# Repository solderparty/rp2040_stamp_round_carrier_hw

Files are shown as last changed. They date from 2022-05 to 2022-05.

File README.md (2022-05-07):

# The RP2040 Stamp Round Carrier

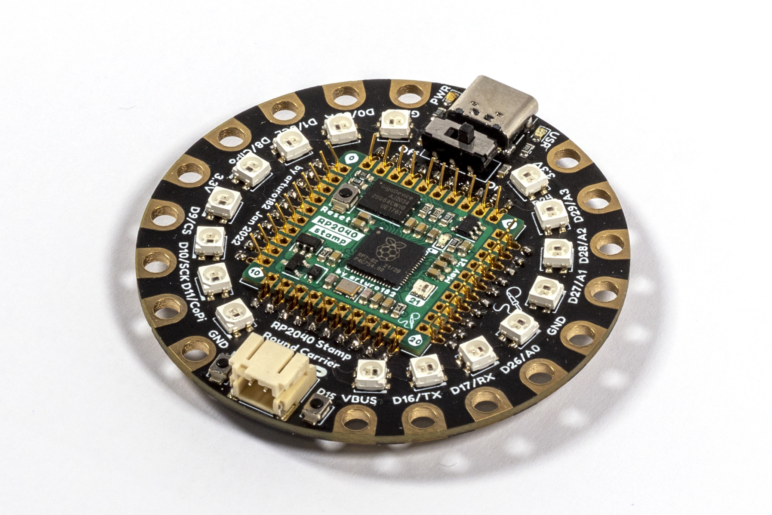
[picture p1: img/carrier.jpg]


The RP2040 Stamp Round Carrier is a reference design for the RP2040 Stamp as well as a full-fledged round RP2040 dev board.
The HW files for the Stamp can be found here: https://github.com/solderparty/rp2040_stamp_hw

The Carrier comes with a combo 3-in-1 SMD/TH/FlexyPin Stamp footprint, you can solder the Stamp directly to the Carrier, use 2mm pin headers + sockets to be able to plug it in and out, or use FlexyPins to pop the Stamp in and out of the Carrier would soldering the Stamp. This way the Carrier also acts as a great Stamp flashing and testing jig.

On top of all the functionality of the Stamp, the Carrier also adds:
* A ring of 16 Neopixels
* Combo 3-in-1 Stamp footprint (SMD/TH/FlexyPin)
* Sewing (conductive thread) and alligator clip-friendly pads
* An on/off switch
* 3.7/4.2V LiPo connector
* USR LED
* Power (3.3V) LED
* Two user buttons
* USB Type-C connector

# Links

For more information visit https://rp2040-stamp.solder.party/

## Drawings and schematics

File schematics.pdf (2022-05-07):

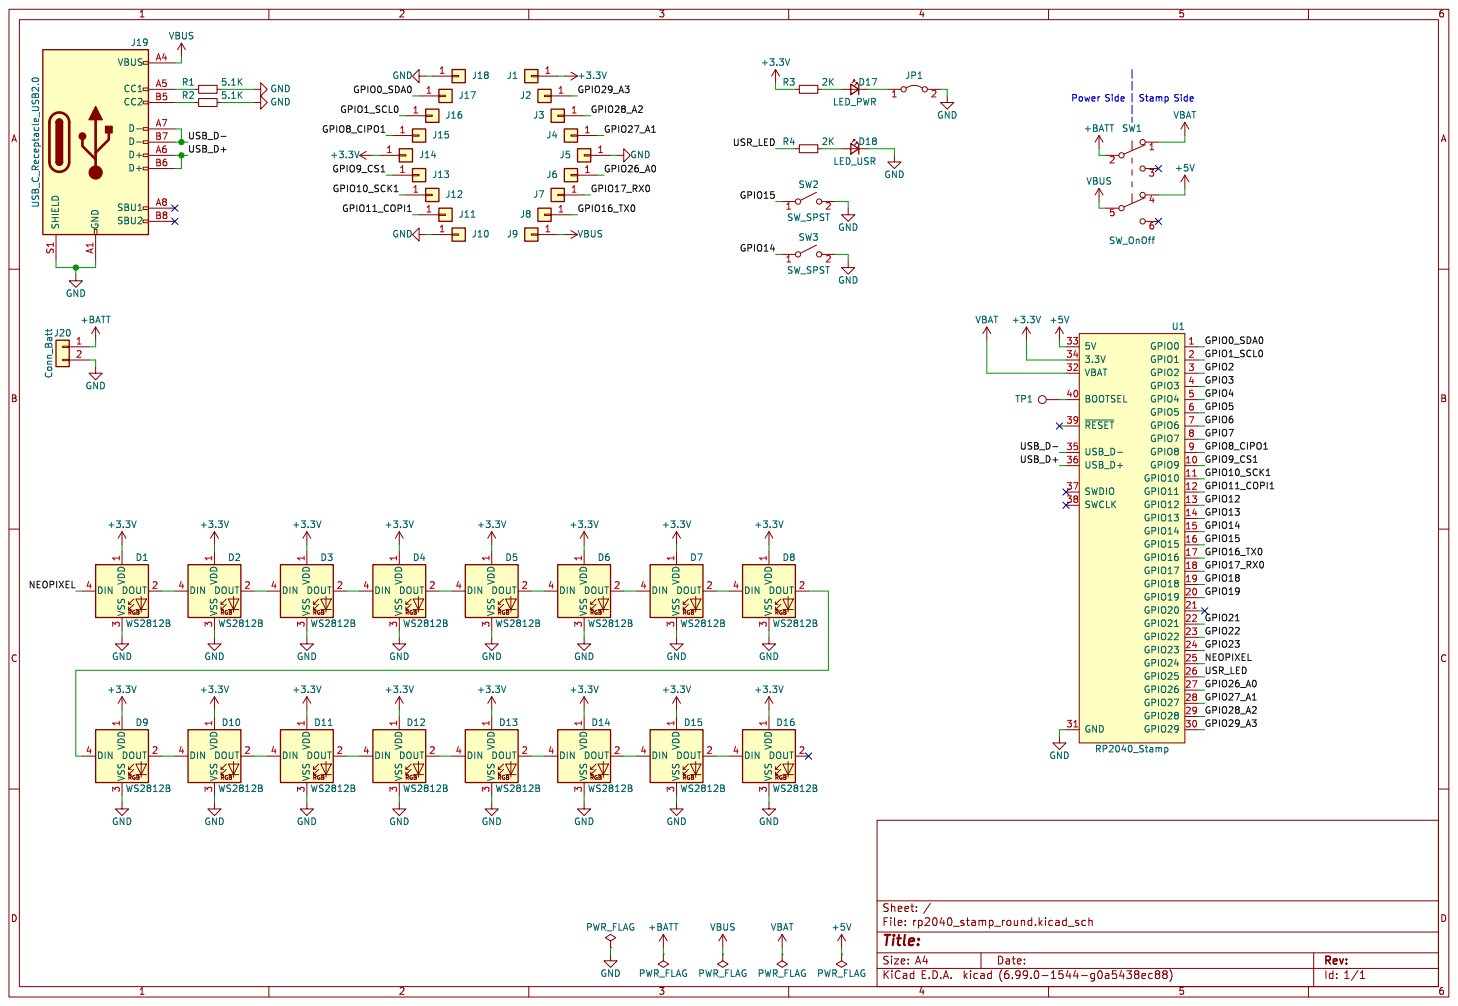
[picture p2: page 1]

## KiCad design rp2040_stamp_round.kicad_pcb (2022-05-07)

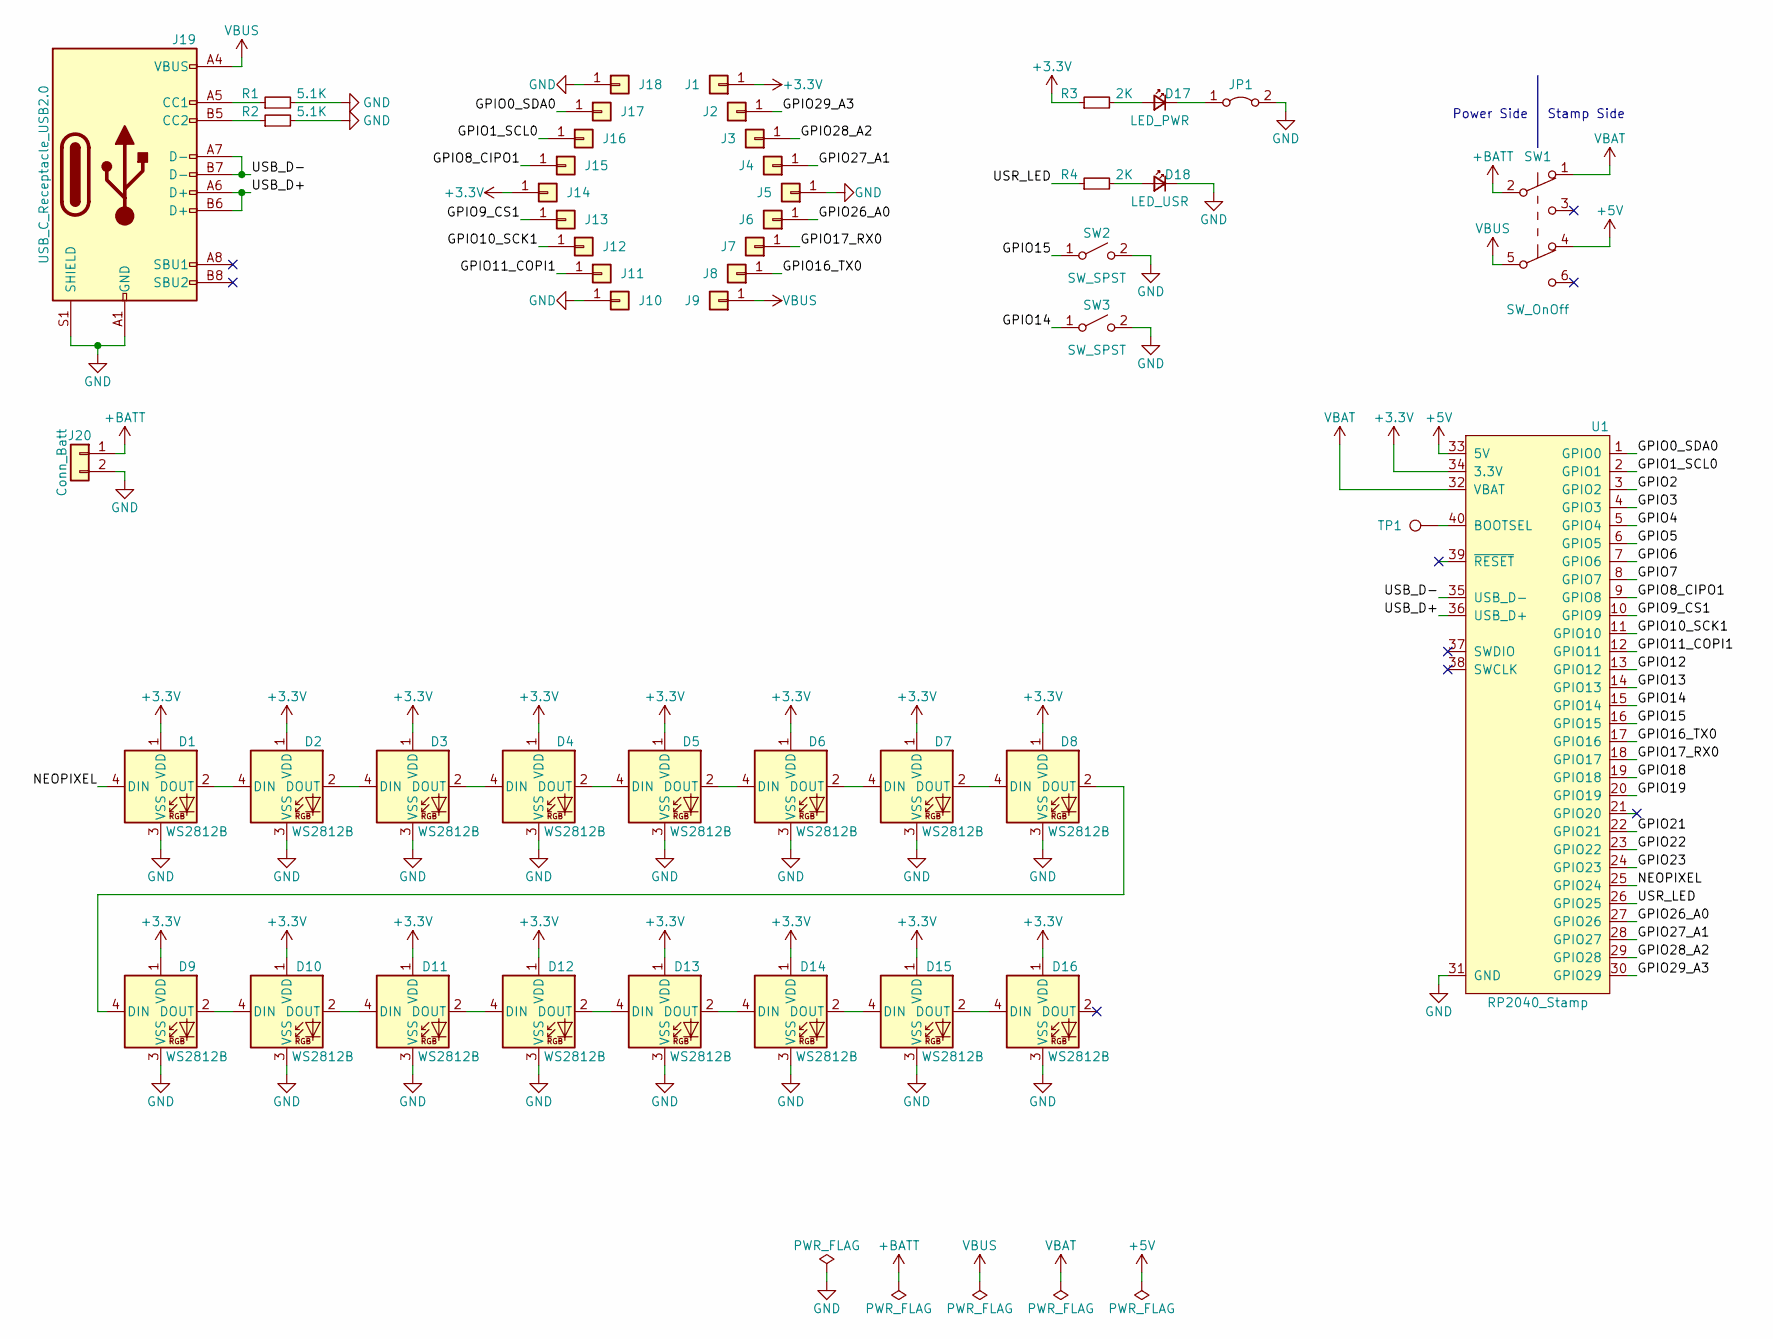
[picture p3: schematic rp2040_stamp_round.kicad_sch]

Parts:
D1, D2, D3, D4, D5, D6, D7, D8, D9, D10, D11, D12, D13, D14, D15, D16: WS2812B; LED_WS2812B_PLCC4_3.5x3.5mm_P1.78mm; LCSC C527089
D17: LED_PWR; LED_0603_1608Metric
D18: LED_USR; LED_0603_1608Metric
J1, J2, J3, J4, J5, J6, J7, J8, J9, J10, J11, J12, J13, J14, J15, J16, J17, J18: Conn_01x01; MountingHole_3.2mm_M3_Pad_Polygon
J19: USB_C_Receptacle_USB2.0; USB_C_Receptacle_XKB_U262-16XN-4BVC11; LCSC C319148
J20: Conn_Batt; JST_PH_S2B-PH-SM4-TB_1x02-1MP_P2.00mm_Horizontal; LCSC C47647
JP1: Jumper_PWR; SolderJumper-2_P1.3mm_Bridged_RoundedPad1.0x1.5mm
R1, R2: 5.1K; R_0603_1608Metric
R3, R4: 2K; R_0603_1608Metric
SW1: SW_OnOff; SW_DPDT_CK_JS202011JCQN; LCSC C221665
SW2, SW3: SW_SPST; SW_SPST_B3U-1000P-B; LCSC C561514
TP1: TP_BOOTSEL; TestPoint_Pad_D2.0mm
U1: RP2040_Stamp; RP2040_Stamp_Springs

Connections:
+3V3: D1.1 (VDD), D2.1 (VDD), D3.1 (VDD), D4.1 (VDD), D5.1 (VDD), D6.1 (VDD), D7.1 (VDD), D8.1 (VDD), D9.1 (VDD), D10.1 (VDD), D11.1 (VDD), D12.1 (VDD), D13.1 (VDD), D14.1 (VDD), D15.1 (VDD), D16.1 (VDD), J1.1, J14.1, R3.1, U1.34 (3.3V)
+5V: SW1.4 (A), U1.33 (5V)
+BATT: J20.1, SW1.2 (B)
/GPIO0_SDA0: J17.1, U1.1 (GPIO0)
/GPIO1_SCL0: J16.1, U1.2 (GPIO1)
/GPIO2: U1.3 (GPIO2)
/GPIO3: U1.4 (GPIO3)
/GPIO4: U1.5 (GPIO4)
/GPIO5: U1.6 (GPIO5)
/GPIO6: U1.7 (GPIO6)
/GPIO7: U1.8 (GPIO7)
/GPIO8_CIPO1: J15.1, U1.9 (GPIO8)
/GPIO9_CS1: J13.1, U1.10 (GPIO9)
/GPIO10_SCK1: J12.1, U1.11 (GPIO10)
/GPIO11_COPI1: J11.1, U1.12 (GPIO11)
/GPIO12: U1.13 (GPIO12)
/GPIO13: U1.14 (GPIO13)
/GPIO14: SW3.1 (A), U1.15 (GPIO14)
/GPIO15: SW2.1 (A), U1.16 (GPIO15)
/GPIO16_TX0: J8.1, U1.17 (GPIO16)
/GPIO17_RX0: J7.1, U1.18 (GPIO17)
/GPIO18: U1.19 (GPIO18)
/GPIO19: U1.20 (GPIO19)
/GPIO21: U1.22 (GPIO21)
/GPIO22: U1.23 (GPIO22)
/GPIO23: U1.24 (GPIO23)
/GPIO26_A0: J6.1, U1.27 (GPIO26)
/GPIO27_A1: J4.1, U1.28 (GPIO27)
/GPIO28_A2: J3.1, U1.29 (GPIO28)
/GPIO29_A3: J2.1, U1.30 (GPIO29)
/NEOPIXEL: D1.4 (DIN), U1.25 (GPIO24)
/USB_D+: J19.A6 (D+), J19.B6 (D+), U1.36 (USB_D+)
/USB_D-: J19.A7 (D-), J19.B7 (D-), U1.35 (USB_D-)
/USR_LED: R4.1, U1.26 (GPIO25)
GND: D1.3 (VSS), D2.3 (VSS), D3.3 (VSS), D4.3 (VSS), D5.3 (VSS), D6.3 (VSS), D7.3 (VSS), D8.3 (VSS), D9.3 (VSS), D10.3 (VSS), D11.3 (VSS), D12.3 (VSS), D13.3 (VSS), D14.3 (VSS), D15.3 (VSS), D16.3 (VSS), D18.1 (K), J5.1, J10.1, J18.1, J19.A1 (GND), J19.A12 (GND), J19.B1 (GND), J19.B12 (GND), J19.S1 (SHIELD), J20.2, JP1.2 (B), R1.2, R2.2, SW2.2 (B), SW3.2 (B), U1.31 (GND)
unnamed: D1.2 (DOUT), D2.4 (DIN)
unnamed: D2.2 (DOUT), D3.4 (DIN)
unnamed: D3.2 (DOUT), D4.4 (DIN)
unnamed: D4.2 (DOUT), D5.4 (DIN)
unnamed: D5.2 (DOUT), D6.4 (DIN)
unnamed: D6.2 (DOUT), D7.4 (DIN)
unnamed: D7.2 (DOUT), D8.4 (DIN)
unnamed: D8.2 (DOUT), D9.4 (DIN)
unnamed: D9.2 (DOUT), D10.4 (DIN)
unnamed: D10.2 (DOUT), D11.4 (DIN)
unnamed: D11.2 (DOUT), D12.4 (DIN)
unnamed: D12.2 (DOUT), D13.4 (DIN)
unnamed: D13.2 (DOUT), D14.4 (DIN)
unnamed: D14.2 (DOUT), D15.4 (DIN)
unnamed: D15.2 (DOUT), D16.4 (DIN)
unnamed: D17.2 (A), R3.2
unnamed: D17.1 (K), JP1.1 (A)
unnamed: D18.2 (A), R4.2
unnamed: J19.A5 (CC1), R1.1
unnamed: J19.B5 (CC2), R2.1
unnamed: TP1.1, U1.40 (BOOTSEL)
VBAT: SW1.1 (A), U1.32 (VBAT)
VBUS: J9.1, J19.A4 (VBUS), J19.A9 (VBUS), J19.B4 (VBUS), J19.B9 (VBUS), SW1.5 (B)

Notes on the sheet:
Stamp Side
Power Side

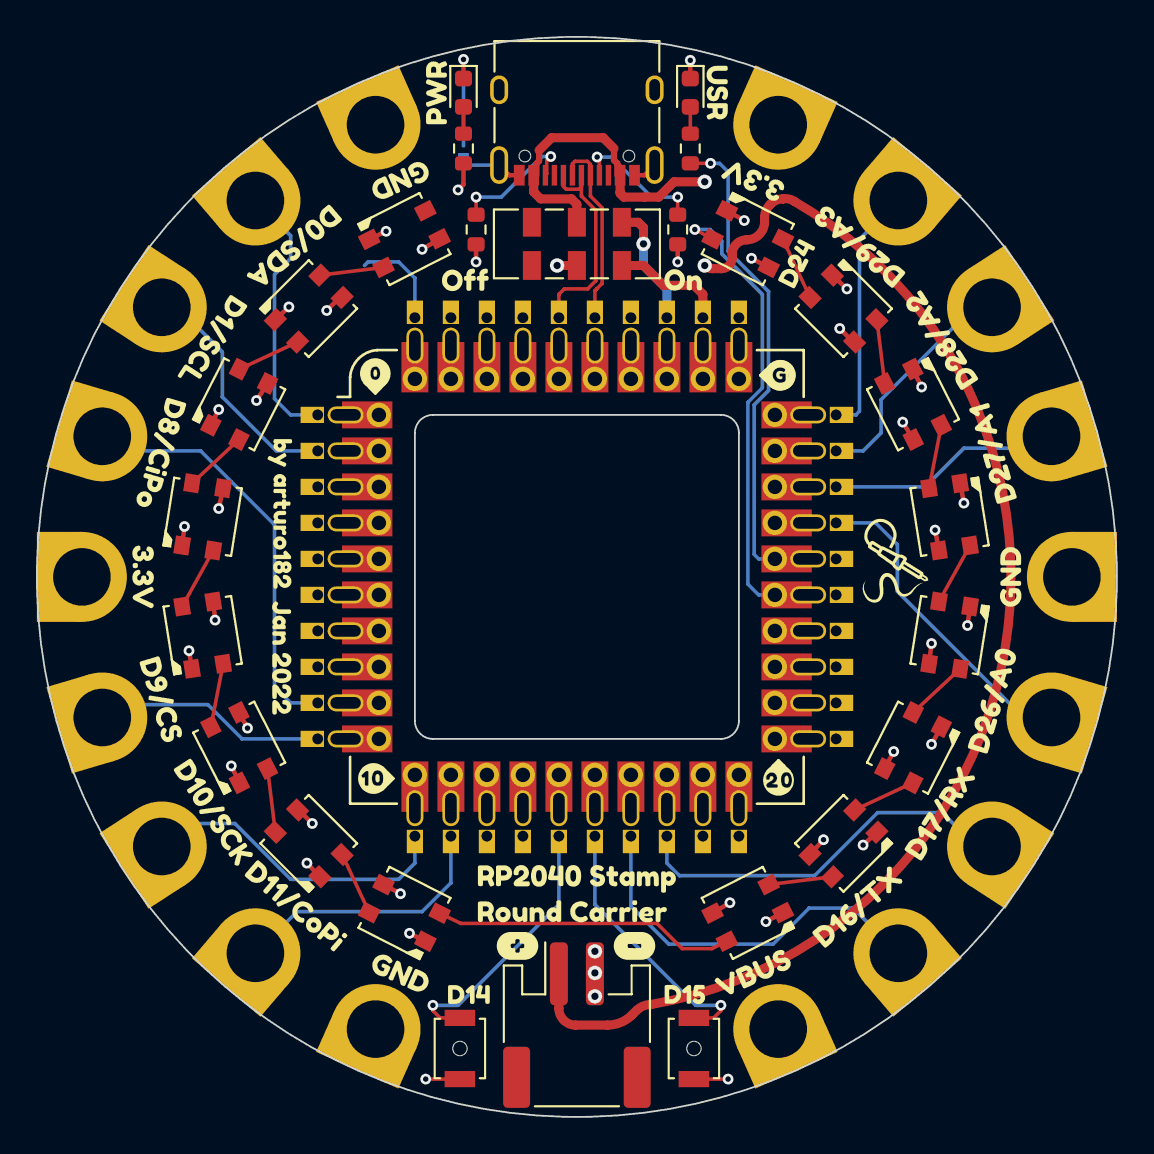
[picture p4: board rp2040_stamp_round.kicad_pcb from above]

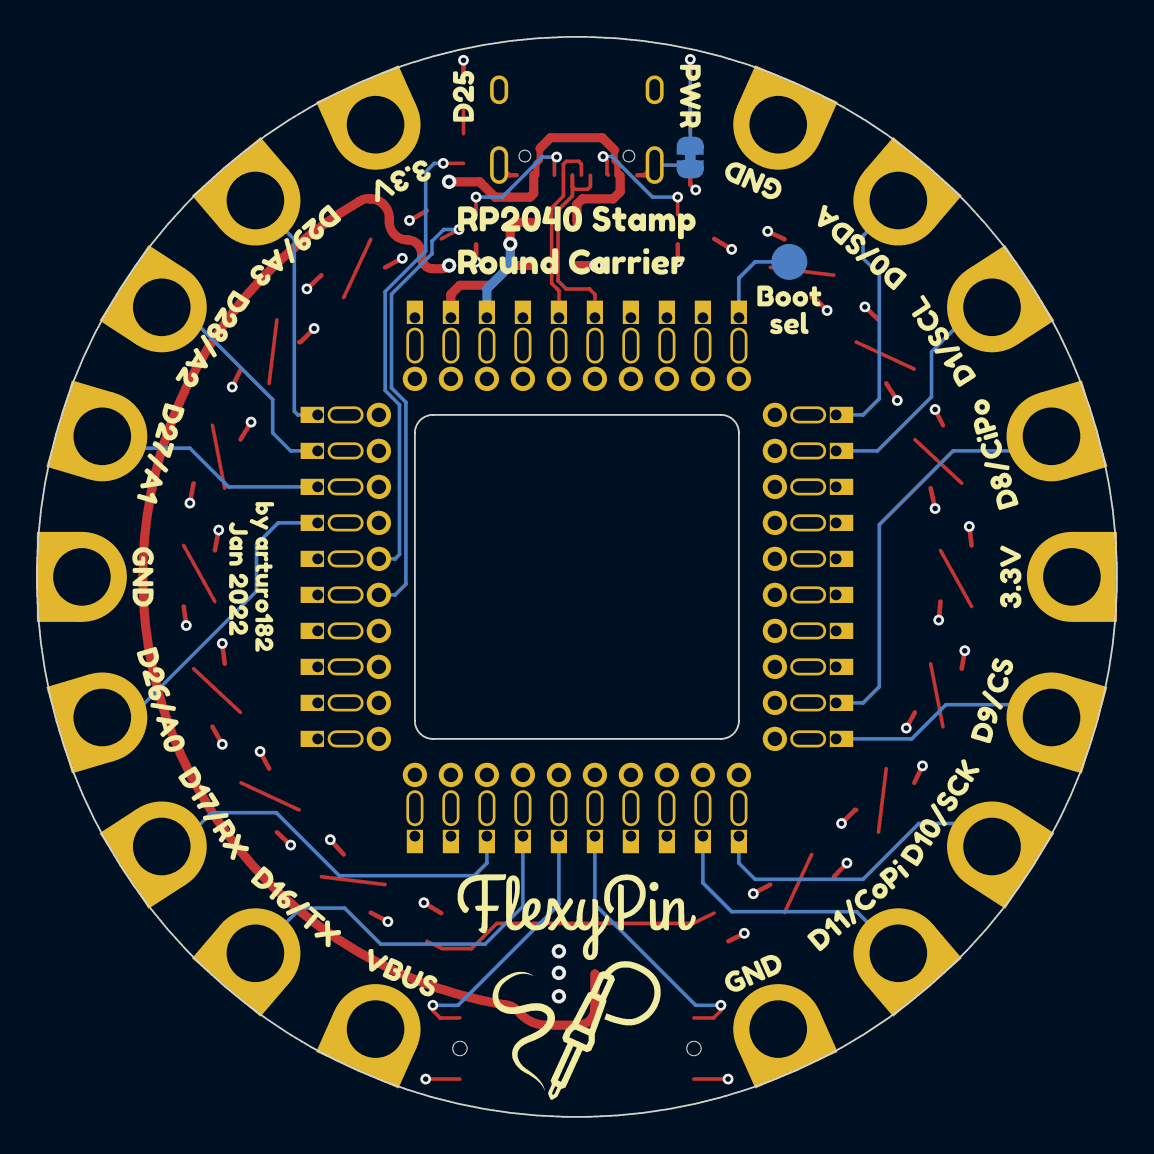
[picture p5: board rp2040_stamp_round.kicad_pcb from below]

Board: 4 copper layers, 60.0 x 60.0 mm, 103 parts (27 on the bottom side), 45 nets.

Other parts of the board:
kibuzzard-61B7CACE, kibuzzard-61B7CACE#2: G***; kibuzzard-61B7CACE
kibuzzard-61B7CB2A, kibuzzard-61B7CB2A#2, kibuzzard-61B7CB2A#3, kibuzzard-61B7CB2A#4: G***; kibuzzard-61B7CB2A
kibuzzard-61B7CB91, kibuzzard-61B7CB91#2, kibuzzard-61B7CB91#3, kibuzzard-61B7CB91#4, kibuzzard-61B7CB91#5, kibuzzard-61B7CB91#6: G***; kibuzzard-61B7CB91
kibuzzard-61B7F7A6, kibuzzard-61B7F7A6#2: G***; kibuzzard-61B7F7A6
kibuzzard-61B7F7BF, kibuzzard-61B7F7BF#2: G***; kibuzzard-61B7F7BF
kibuzzard-61B7F7D5, kibuzzard-61B7F7D5#2: G***; kibuzzard-61B7F7D5
kibuzzard-61B7F7FD, kibuzzard-61B7F7FD#2: G***; kibuzzard-61B7F7FD
kibuzzard-61B7F819, kibuzzard-61B7F819#2: G***; kibuzzard-61B7F819
kibuzzard-61B7FA9B, kibuzzard-61B7FA9B#2: G***; kibuzzard-61B7FA9B
kibuzzard-61B7FAB5, kibuzzard-61B7FAB5#2: G***; kibuzzard-61B7FAB5
kibuzzard-61B7FADB, kibuzzard-61B7FADB#2: G***; kibuzzard-61B7FADB
kibuzzard-61B7FB04, kibuzzard-61B7FB04#2: G***; kibuzzard-61B7FB04
kibuzzard-61B7FB19, kibuzzard-61B7FB19#2: G***; kibuzzard-61B7FB19
kibuzzard-61B7FB48, kibuzzard-61B7FB48#2: G***; kibuzzard-61B7FB48
kibuzzard-61B7FFB7: G***; kibuzzard-61B7FFB7
kibuzzard-61B788A5, kibuzzard-61B788A5#2: G***; kibuzzard-61B788A5
kibuzzard-61B789B2: G***; kibuzzard-61B789B2
kibuzzard-61B804DF: G***; kibuzzard-61B804DF
kibuzzard-61B804E7: G***; kibuzzard-61B804E7
kibuzzard-61B8067D: G***; kibuzzard-61B8067D
kibuzzard-61B8084E: G***; kibuzzard-61B8084E
kibuzzard-61B78991: G***; kibuzzard-61B78991
kibuzzard-61B80856: G***; kibuzzard-61B80856
kibuzzard-61BA2B21, kibuzzard-61BA2B21#2: G***; kibuzzard-61BA2B21
kibuzzard-61BA4CE2: G***; kibuzzard-61BA4CE2
kibuzzard-61DD95B3: G***; kibuzzard-61DD95B3
kibuzzard-61DD95E6: G***; kibuzzard-61DD95E6
kibuzzard-61DD95F0: G***; kibuzzard-61DD95F0
kibuzzard-61DD9534, kibuzzard-61DD9534#2: G***; kibuzzard-61DD9534
kibuzzard-61DD9594: G***; kibuzzard-61DD9594
kibuzzard-61E0313F: G***; kibuzzard-61E0313F
kibuzzard-61E03091: G***; kibuzzard-61E03091

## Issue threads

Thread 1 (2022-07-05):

Power Switch & Charging

cooltrooper, 2022-07-05:
Hello,

Just to check my understanding, due to the design of the stamp and this carrier, charging of the battery only takes place when the power switch is on?

Thanks

arturo182, 2022-07-06:
Yes, that is correct. The power switch disconnects the battery and the USB power. This is by design :)

Closed 2022-07-06.

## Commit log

2021-12-15 Rev 1
    [rp2040_stamp_round.kicad_pcb, rp2040_stamp_round.kicad_sch]
2022-05-07 Production rev release
    [rp2040_stamp_round.kicad_pcb, rp2040_stamp_round.kicad_sch]
2022-06-21 Fix stamp footprint submodule
